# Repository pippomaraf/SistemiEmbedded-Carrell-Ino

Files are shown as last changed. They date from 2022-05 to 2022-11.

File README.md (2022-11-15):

# Carrell-Ino

### Descrizione

##### Autore

Filippo Maraffio

##### Descrizione

Il progetto prevede la realizzazione di un carrello elettrico automatico, in grado di spostare piccoli oggetti, lungo un percorso prefissato.

Il "Carrell-Ino" partirà automaticamente quando rileverà la presenza di un oggetto nel suo "cassone", e si muoverà seguendo una linea marcata precedentemente sul pavimento con del nastro isolante scuro.

Raggiunta la sua destinazione, il "Carrell-Ino" si fermerà, in attesa di essere scaricato.

Una volta che il suo cassone sarà libero, il "Carrell-Ino" tornerà al punto di partenza, pronto per essere caricato nuovamente.

##### Istruzioni di utilizzo

1. Tracciare un percorso, delineato da una linea scura, su una superficie chiara (ad esempio, utilizzare del nastro isolante nero su un pavimento di legno). Alle estremità del percoso posizionare delle sagome verticali (ad esempio, delle scatole di cartone)  per delimitare inizio e fine tratto.  Posizionare il "Carrell-Ino" a cavallo della linea che traccia il tragitto, ed accenderlo.

2. Posizionare un peso di almeno 50g sulla bilancia presente sul pannello superiore del "Carrell-Ino" ed attendere. Dopo pochi istanti, il carrello emetterà un segnale acustico e luminoso ed inizierà a muoversi.

3. Il "Carrell-Ino" si muoverà seguendo il percorso prefissato e si fermerà automaticamente una volta raggiunta la sua destinazione. Una luce rossa si accenderà per richiedere l'intervento dell'utente.

4. Girare il "Carrell-Ino", in modo tale da orientarlo verso il punto di partenza e premere il pulsante di cambio stato, posizionato vicino al sensore ad ultrasuoni.

5. Il "Carrell-Ino", dapprima resterà in attesa di essere scaricato; quando non rileverà più il peso sulla bilancia, ripartirà tornando al punto di inizio, dove si fermerà. 

6. Premendo il pulsante il "Carrell-Ino" tornerà al suo stato iniziale, e, dopo averlo riposizionato, sarà possibile caricarlo e farlo ripartire per effettuare ulteriori viaggi.

##### Calibrazione bilancia

Quando si installa una nuova cella di carico sul Carrell-Ino, è opportuno effettuare una calibrazione della bilancia, così da evitare comportamenti anomali.

Per la calibrazione, procurarsi un oggetto dal peso noto, collegare il Carrell-Ino a un PC dove è installato Arduino IDE, scommentare la costante `SCALE_CALIBRATION` e impostare `LOADCELL_DIVIDER` a `1`. Caricare quindi lo sketch modificato sulla board, aprire il serial monitor e seguire le istruzioni che compariranno a schermo.

Dopo aver effettuato tutti i passaggi, dividere il numero restituito dal serial monitor per il peso dell'oggetto usato per la calibrazione e usarlo come valore della costante `LOADCELL_DIVIDER`. Ricommentare `SCALE_CALIBRATION` e caricare nuovamente lo sketch sulla board. Il Carrell-Ino è pronto a partire!

##### Hardware utilizzato

- Board: Arduino Uno

- 4x modulo di rilevamento linea KY-033 (con sensore a infrarossi TCRT5000)

- 1x sensore a ultrasuoni HC-SR04

- 1x cella di carico 0-5kg

- 1x moudlo ADC HX711 (per amplificare e convertire il segnale della cella di carico)

- 1x Motor driver L298N

- 2x motori CC da 6V

- 5x batterie AA da 1.5V  (7.5V totali)

- 1x pulsante

- 1x diodo led

- 1x resistore da 1000 Ohm

- 1x  buzzer passivo

Per la la realizzazione del telaio e del ruotino di coda sono state utilizzate una  scatola di derivazione elettrica da incasso e una rotella girevole per mobili.

##### Librerie utilizzate

- [GitHub - bogde/HX711: An Arduino library to interface the Avia Semiconductor HX711 24-Bit Analog-to-Digital Converter (ADC) for Weight Scales.](https://github.com/bogde/HX711)

---

### Progettazione

Il programma che controlla il Carrell-Ino può essere descritto, ad alto livello, tramite il seguente automa a stati finiti:

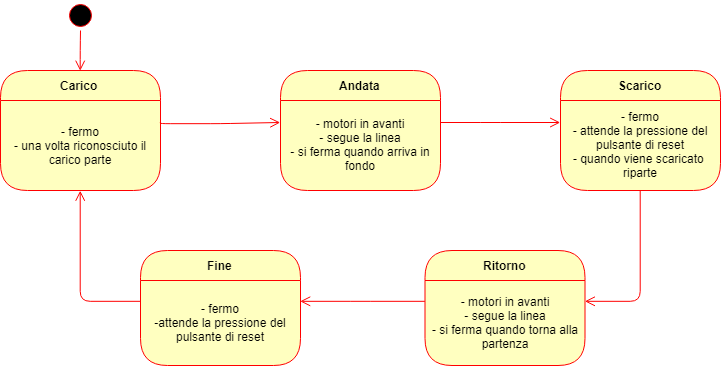
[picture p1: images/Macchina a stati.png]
Macchina a stati.png


_Schema della macchina a stati finiti utilizzata per gestire le varie fasi di esecuzione._

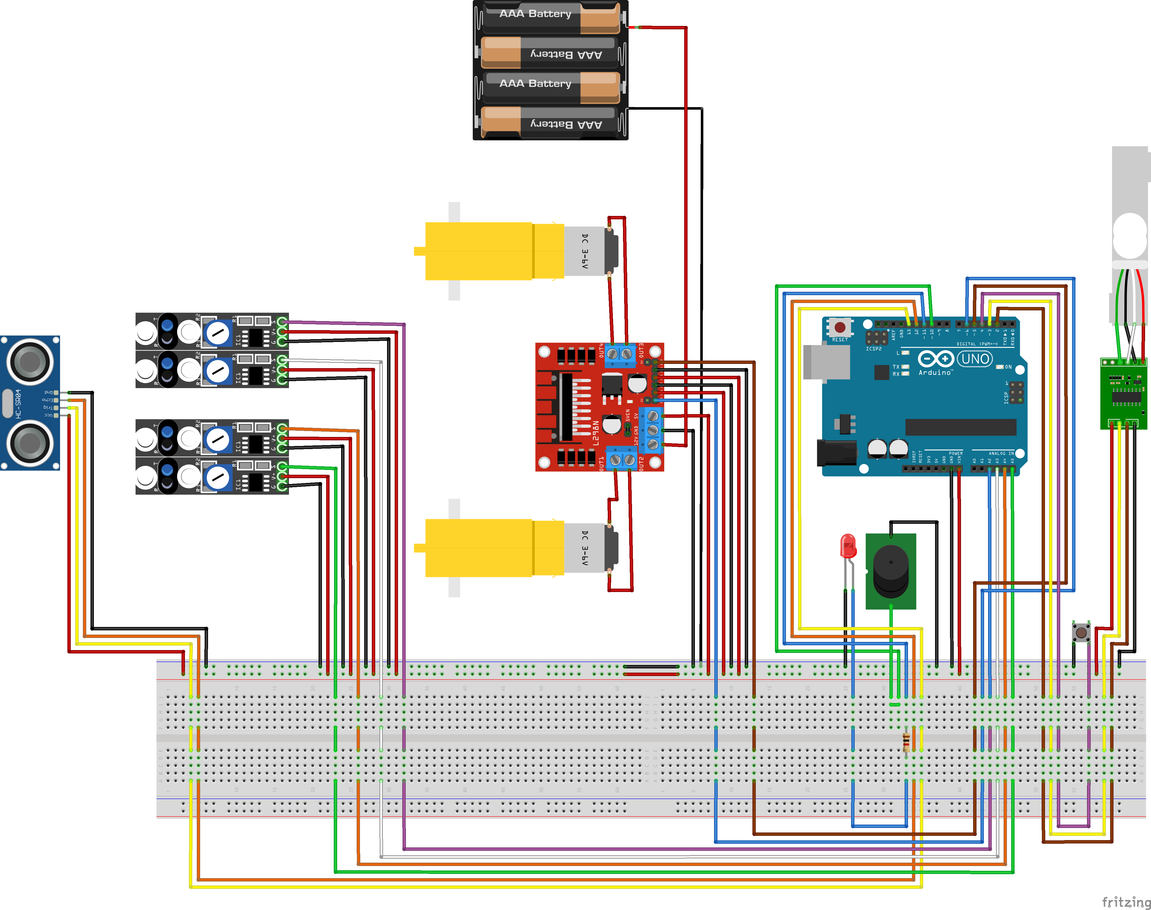
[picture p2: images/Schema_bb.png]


_Schema circuitale. Immagine creata con [Fritzing](https://fritzing.org/)_

---

### Foto e video

Un video del Carrell-Ino in funzione può essere trovato al seguente link: [Carrell-Ino - YouTube](https://www.youtube.com/watch?v=kGcqHUkBG_E)

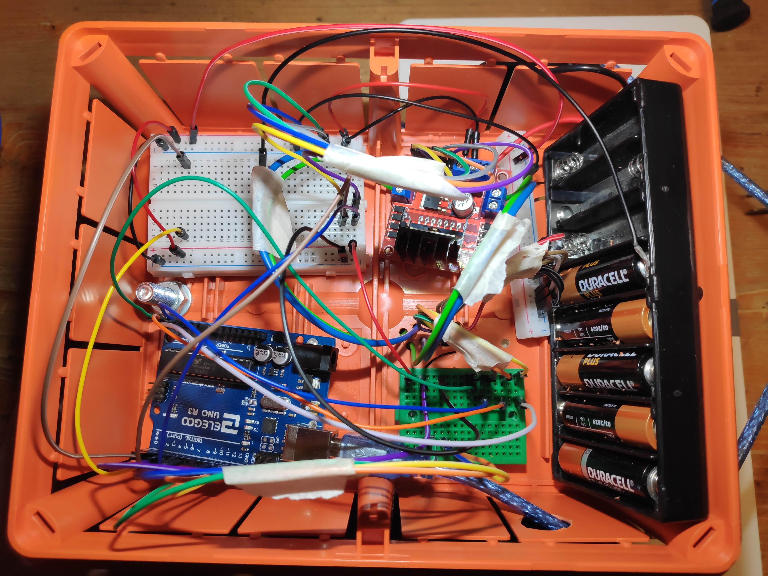
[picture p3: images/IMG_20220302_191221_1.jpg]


_Struttura interna del Carrell-Ino. Sono visibili la board Arduino Uno, il pacco batterie e il Motor Driver L298N._

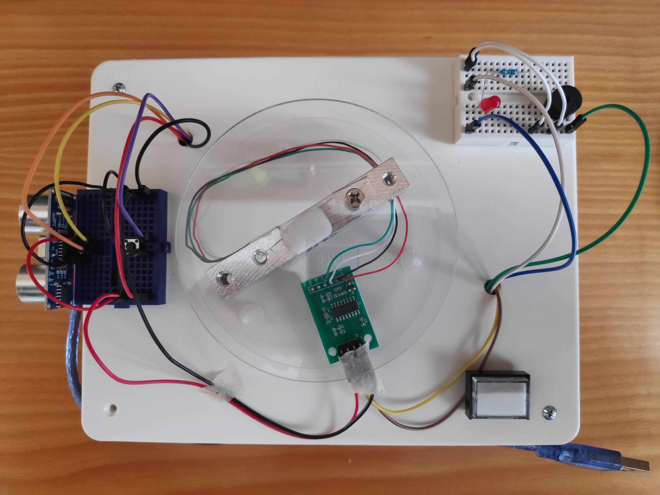
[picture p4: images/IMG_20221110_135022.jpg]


_Pannello superiore: sulla sinistra sono presenti il sensore a ultrasuoni e il pulsante per il cambio di stato, al centro si trova la cella di carico e il rispettivo moudlo ADC HX711, mentre a destra possiamo vedere il pulsante di accensione e il blocco di output._

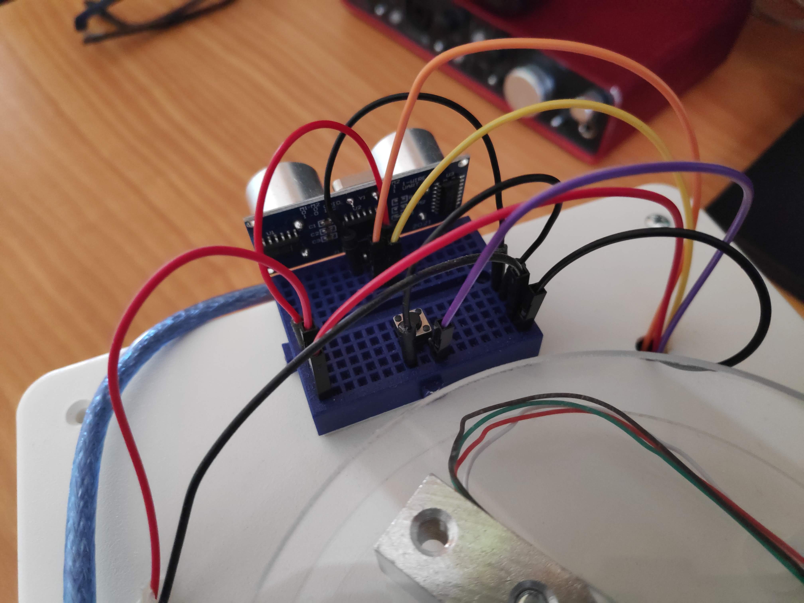
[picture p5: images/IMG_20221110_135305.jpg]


_Particolare del sensore a ultrasuoni e del pulsante di cambio stato._

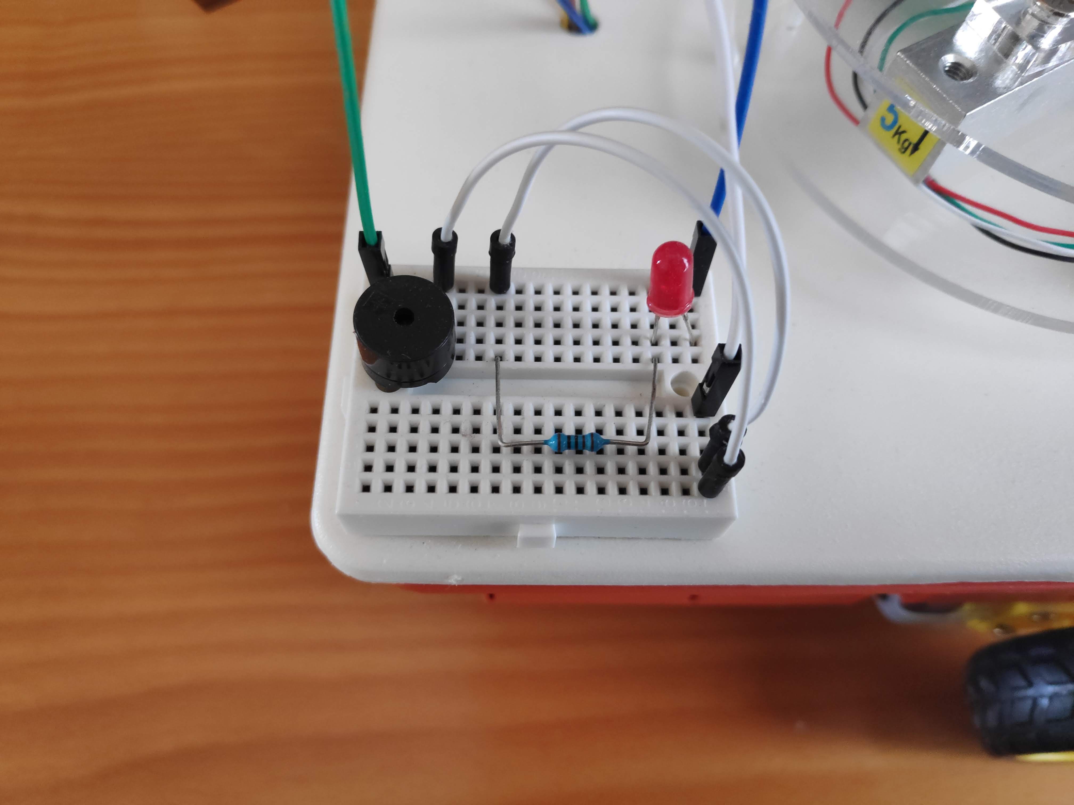
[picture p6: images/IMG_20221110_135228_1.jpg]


_Particolare del blocco di output: sono osservabili il diodo led con il suo resistore e il buzzer passivo._

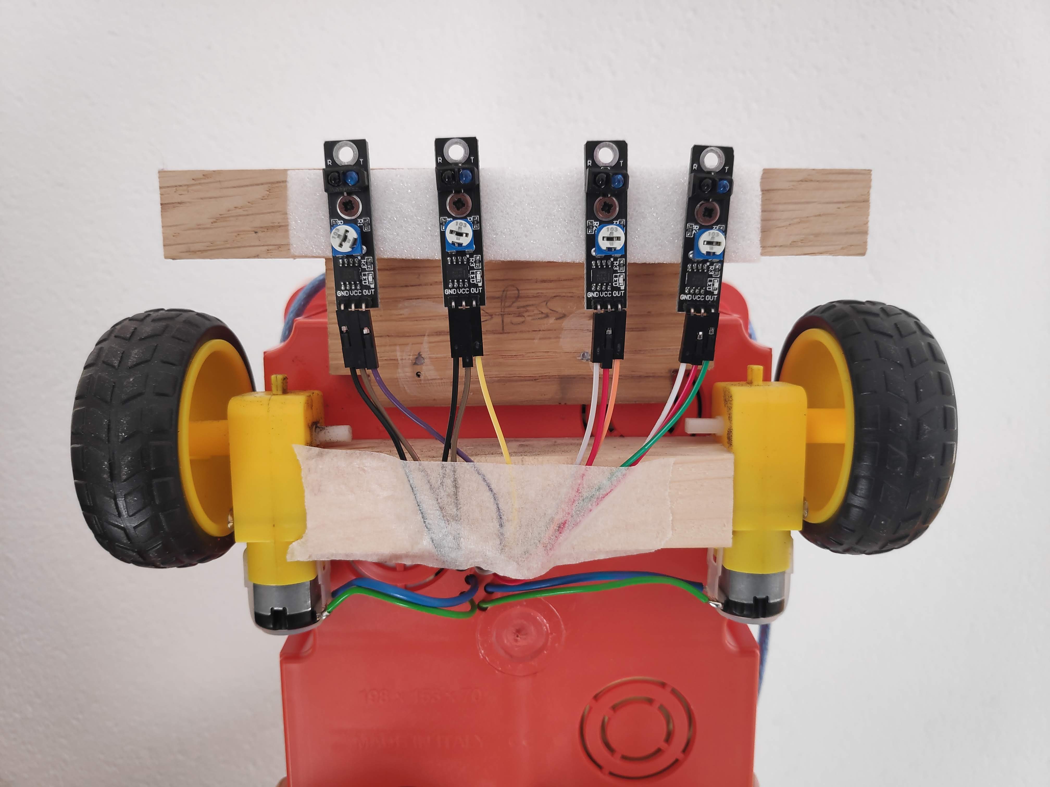
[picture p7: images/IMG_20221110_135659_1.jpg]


_Posizionamento dei moduli di rilevamento linea e dei due motori a corrente continua._

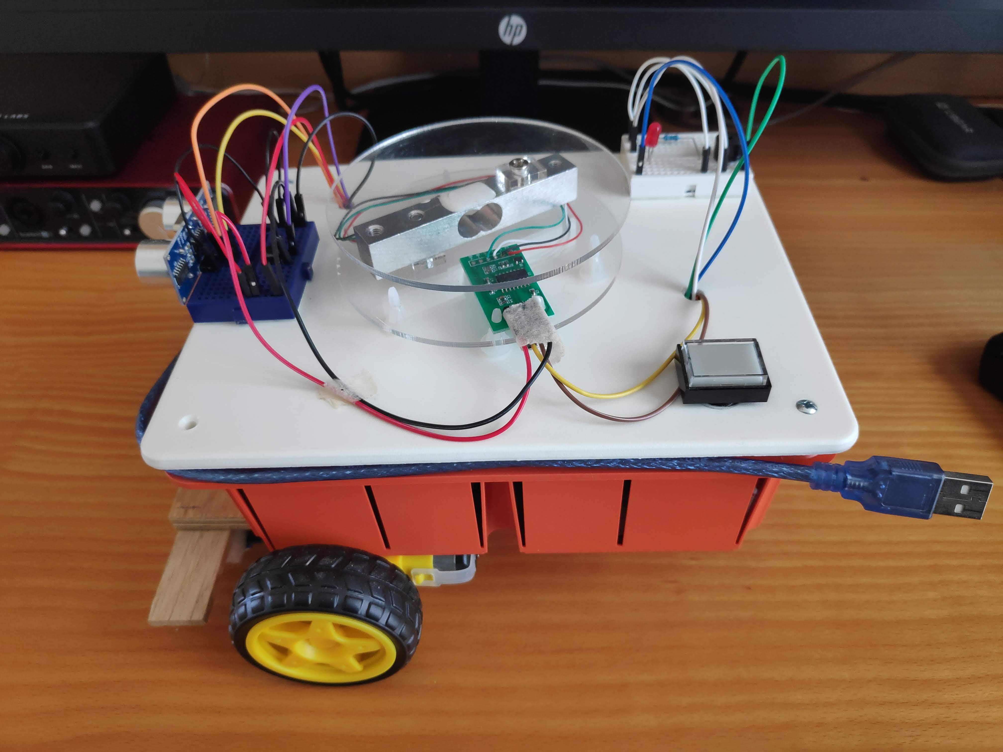
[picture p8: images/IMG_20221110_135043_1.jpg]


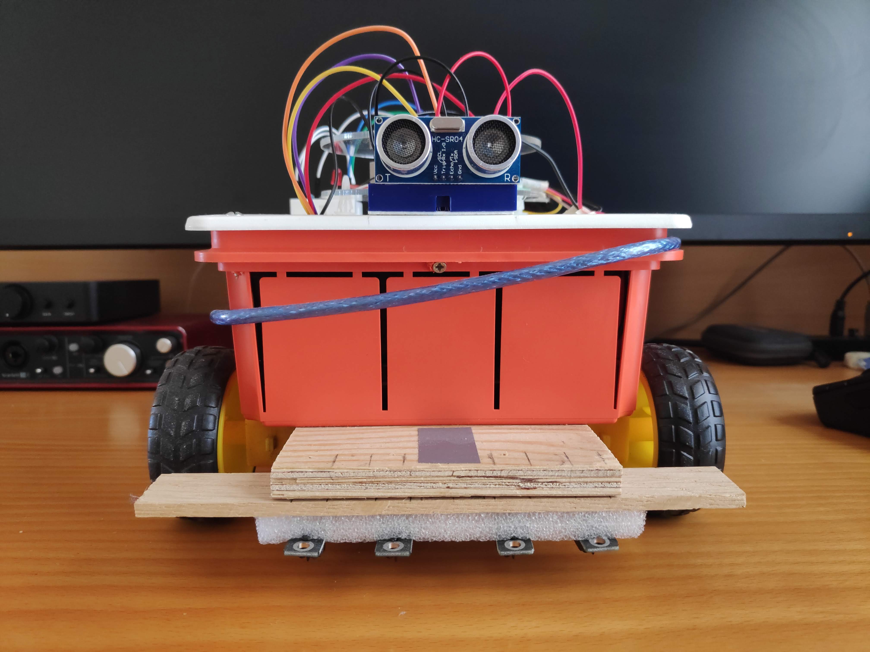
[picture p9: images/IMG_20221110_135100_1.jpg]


_Viste laterale e anteriore del Carrell-Ino._

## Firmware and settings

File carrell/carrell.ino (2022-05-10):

/**
 * @file carrell.ino
 * @author Filippo Maraffio
 * @brief Automatic, line-following electric cart
 * @version 1.0
 */

#include "HX711.h"
HX711 loadcell;

//-----------------------------
//      GPIO DEFINITIONS
//-----------------------------

// HC-SR04 ultrasonic sensor
#define ULTRASONIC_TRIG 13
#define ULTRASONIC_ECHO 12

// KY-033 line detecting sensor
// note: due to digital pin shortage, analog pins are used
// to perform digitalReads;
#define LINE_FOLLOWER_RR_SIGNAL A5
#define LINE_FOLLOWER_R_SIGNAL A4
#define LINE_FOLLOWER_L_SIGNAL A3
#define LINE_FOLLOWER_LL_SIGNAL A2

// L298N DC motor driver
// note: PWM capable pin needed
// note: the motors only need to move in one direction,
// IN pins are hard-coded (IN1 = IN3 = HIGH, IN2 = IN4 = LOW)
#define MOTOR_DRIVER_ENA 6
#define MOTOR_DRIVER_ENB 5

// HX711 load cell module
#define LOAD_CELL_CK 3
#define LOAD_CELL_DATA 2

// led
#define LED_PIN 11

// button
#define BUTTON_PIN 4

// buzzer
#define BUZZER_PIN 10

//-----------------------------
//      CONSTANTS
//-----------------------------

// uncomment to calibrate the scale
// #define SCALE_CALIBRATION

// load cell calibration, calculated with the calibrateScale() function
#define LOADCELL_DIVIDER 497.5
#define LOADCELL_READ_TIMES 10

// found by trial and error
#define MINIMUM_SPEED 120 // PWM value, out of 255
#define NORMAL_SPEED 130
#define TUNRING_SPEED 20
#define BRAKE_DELAY 3 // milliseconds

// note: measure errors are present. Consider the minimum weight
// to be 10g above this treshold
#define MINIMUM_WEIGHT_TRESHOLD 40

// how many readings of the loadcell to do
#define LOADCELL_READS 10

// number of loadcell reds under the treshold before
// the carrell.ino will start moving
#define CHECKS_BEFORE_START 3

// for stability
#define STABILITY_DELAY 50

// for ultrasonic sensor
#define CLEAR_TIME 2    // microseconds
#define TRIGGER_TIME 10 // microseconds

// number of centimeters travelled by sound in a microsecond
#define CM_MULTIPLIER 0.034326
// 2, to take in consideration the fact that sound has to travel doble the
// distance to go and come back
#define RTT_MULTIPLIER 2
#define STOPPING_DISTANCE 25L // centimeters
#define ERROR_DISTANCE 2L     // centimeters

// return value
#define SUCCESS 1
#define FAILURE -1

//-----------------------------
//      FUNCTIONS
//-----------------------------

/* L298N Motor driver
  Existing libraries are way too complex for what we'll need, so we'll just
  define a couple of functions.

  Our project only needs to move forward, so pins 1,2,3 and 4 are hard-coded
*/
void moveForward(int speed)
{
  analogWrite(MOTOR_DRIVER_ENA, speed);
  analogWrite(MOTOR_DRIVER_ENB, speed);
}

void steer(int speedLeft, int speedRight)
{
  analogWrite(MOTOR_DRIVER_ENA, speedLeft);
  analogWrite(MOTOR_DRIVER_ENB, speedRight);
}

// gently slow down
void stop()
{
  for (int i = NORMAL_SPEED; i >= 0; i--)
  {
    moveForward(i);
    delay(BRAKE_DELAY);
  }
}

/* Tunes
 * the function tone() is used. If you are interested to better understand the
 * tunes, tone(PIN, FREQUENCY, DURATION) plays a tone at FREQUENCY Hz for
 * DURATION ms -> es:   tone(BUZZER_PIN, 494, 700); plays a tune at 494Hz
 * for 700ms
 */
void arrivalTune()
{
  digitalWrite(LED_PIN, HIGH);
  delay(50);
  digitalWrite(LED_PIN, LOW);
  tone(BUZZER_PIN, 494, 700); // B4
  delay(80);

  digitalWrite(LED_PIN, HIGH);
  delay(50);
  digitalWrite(LED_PIN, LOW);
  tone(BUZZER_PIN, 659, 600); // E5
  delay(80);

  digitalWrite(LED_PIN, HIGH);
  delay(50);
  digitalWrite(LED_PIN, LOW);
  tone(BUZZER_PIN, 740, 600); //  F#5
  delay(80);

  digitalWrite(LED_PIN, HIGH);
  tone(BUZZER_PIN, 988, 850); // B5
  delay(850);
  digitalWrite(LED_PIN, LOW);
}

void startTune()
{
  for (int i = 0; i <= 3; i++)
  {
    digitalWrite(LED_PIN, HIGH);
    tone(BUZZER_PIN, 1319, 200); // E6
    delay(200);
    tone(BUZZER_PIN, 1397, 200); // F6
    delay(200);
    digitalWrite(LED_PIN, LOW);
    tone(BUZZER_PIN, 2637, 200); // E7
    delay(200);
    tone(BUZZER_PIN, 2794, 200); // F7
    delay(200);
  }
}

/** Scale
 * to initialize the scale, uncomment the SCALE_CALIBRATION definition and set
 * LOADCELL_DIVIDER to 1.
 */
void calibrateScale()
{
  // calibration start
  bool stopped;
  Serial.println("Begin calibration. Please remove any weight on the scale.");
  Serial.println("Send anything from serial monitor when you are ready");
  stopped = true;
  // clear serial
  while (Serial.available())
  {
    char foo = Serial.read();
  }
  while (stopped)
  {
    if (Serial.available() > 0)
    {
      stopped = false;
    }
  }
  loadcell.tare();
  Serial.println("Put a known weight on the scale, then send anything from the serial monitor");
  stopped = true;
  // clear serial
  while (Serial.available())
  {
    char foo = Serial.read();
  }
  while (stopped)
  {
    if (Serial.available() > 0)
    {
      stopped = false;
    }
  }
  Serial.print("Weight: ");
  Serial.println(loadcell.get_units(LOADCELL_READ_TIMES), 2); // limit to two numbers afer comma
  Serial.println("Divide this for the known weight and set LOADCELL_DIVIDER accordingly");
  Serial.println("Calibration ended");
}

/** LINE FOLLOWER
 * @brief moves forward at the given speed. Carrell.ino will try it's best to
 * follow a dark line on a light surface, using its infrared sensors. To
 * function properly this function should be cycled for the time that you
 * intend the carrell.ino to follow the line. Keep in mind that the infrared
 * sensor are checked in order every cycle, the busyer the cycle you put this
 * function in the slower the carrell.ino will respond!
 */
void followLine(int speed)
{
  // when R sensor is on the line, for the time that it reads the line
  // gently steer right
  if (digitalRead(LINE_FOLLOWER_R_SIGNAL))
  {
    while (digitalRead(LINE_FOLLOWER_R_SIGNAL))
    {
      steer(speed, TUNRING_SPEED);
      // if it gets stuck, break out of the cycle
      if (digitalRead(LINE_FOLLOWER_L_SIGNAL))
        break;
      // if it's very off, steer hard until the left sensor is on the line
      if (digitalRead(LINE_FOLLOWER_RR_SIGNAL))
      {
        while (!digitalRead(LINE_FOLLOWER_L_SIGNAL))
        {
          steer(MINIMUM_SPEED, 0);
        }
      }
    }
  }
  // when L sensor is on the line, for the time that it reads the line
  // gently steer left
  else if (digitalRead(LINE_FOLLOWER_L_SIGNAL))
  {
    while (digitalRead(LINE_FOLLOWER_L_SIGNAL))
    {
      steer(TUNRING_SPEED, speed);
      // if it gets stuck, break out of the cycle
      if (digitalRead(LINE_FOLLOWER_R_SIGNAL))
        break;
      // if it's very off, steer hard until the right sensor is on the line
      if (digitalRead(LINE_FOLLOWER_LL_SIGNAL))
      {
        while (!digitalRead(LINE_FOLLOWER_R_SIGNAL))
        {
          steer(0, MINIMUM_SPEED);
        }
      }
    }
  }
  // if it's very off, steer hard until it's straight again
  else if (digitalRead(LINE_FOLLOWER_RR_SIGNAL))
  {
    while (!digitalRead(LINE_FOLLOWER_L_SIGNAL))
    {
      steer(MINIMUM_SPEED, 0);
    }
  }
  else if (digitalRead(LINE_FOLLOWER_LL_SIGNAL))
  {
    while (!digitalRead(LINE_FOLLOWER_R_SIGNAL))
    {
      steer(0, MINIMUM_SPEED);
    }
  }
  // otherwise, go straight
  else if (!digitalRead(LINE_FOLLOWER_R_SIGNAL) && !digitalRead(LINE_FOLLOWER_L_SIGNAL))
    moveForward(speed);
}

/** ULtrasoun sensor
 * @brief check if a wall is near in front of the carrell.ino
 * Stop if needed
 */
int stopIfNearWall()
{
  // start in a safe state
  digitalWrite(ULTRASONIC_TRIG, LOW);
  delayMicroseconds(CLEAR_TIME);

  // send ultrasonic signal
  digitalWrite(ULTRASONIC_TRIG, HIGH);
  delayMicroseconds(TRIGGER_TIME);
  digitalWrite(ULTRASONIC_TRIG, LOW);

  // read echo value, in microseconds
  long duration = pulseIn(ULTRASONIC_ECHO, HIGH, 2000);

  // Calculating the distance in cm
  long distance = duration * CM_MULTIPLIER / RTT_MULTIPLIER;

  // if there are less than the desired distance, stop and go to unloading state
  if (distance > ERROR_DISTANCE && distance < STOPPING_DISTANCE)
  {
    stop();
    return SUCCESS;
  }
  return FAILURE;
}

//-----------------------------
//      STATES
//-----------------------------
/**
 * @brief the carrell.ino is stopped. Once a load of at least
 * 50 grams is put on the
 * scale, the start sequence will be played
 */
void loadingState()
{
  long weight = 0L;
  int times = CHECKS_BEFORE_START;

  while (times >= 0)
  {
    Serial.println(times);
    Serial.print("Weight: ");
    weight = loadcell.get_units(LOADCELL_READS);
    Serial.println(weight);
    if (weight >= MINIMUM_WEIGHT_TRESHOLD)
    {
      times--;
    }
    else
    {
      times = CHECKS_BEFORE_START;
    }
  }
  startTune();
}

/**
 * @brief carrell.ino starts moving. It will follow a black line on the floor,
 * and it will stop when a  wall is near in front of it.
 */
void wayThereState()
{
  // start moving forward
  while (true)
  {
    followLine(NORMAL_SPEED);
    int returnValue = stopIfNearWall();
    if (returnValue == SUCCESS)
      break;
  }
}

/**
 * @brief the carrell.ino has stopped. First, you'll need to turn it around
 * (due to the limited number of GPIO the carrell.ino does not have a symmetric
 * structure), then you'll need to press the button near the ultrasonic sensor.
 * The carrell.ino will wait to be unloaded, then it will go back to where it
 * started its run.
 */
void unloadingState()
{
  // wait until the reset button is pressed
  while (true)
  {
    if (!digitalRead(BUTTON_PIN))
    {
      break;
    };
    digitalWrite(LED_PIN, HIGH);
    delay(STABILITY_DELAY);
  }
  digitalWrite(LED_PIN, LOW);

  long weight = 0L;
  int times = CHECKS_BEFORE_START;

  while (times >= 0)
  {
    weight = loadcell.get_units(LOADCELL_READS);
    if (weight <= MINIMUM_WEIGHT_TRESHOLD)
    {
      times--;
    }
    else
    {
      times = CHECKS_BEFORE_START;
    }
  }
  startTune();
}

void wayBackState()
{
  while (true)
  {
    followLine(NORMAL_SPEED);
    int returnValue = stopIfNearWall();
    if (returnValue == SUCCESS)
      break;
  }
}

void finishState()
{
  arrivalTune();
  while (true)
  {
    if (!digitalRead(BUTTON_PIN))
      break;
    delay(STABILITY_DELAY);
  }
}

//-----------------------------
//      LOOP AND SETUP
//-----------------------------

void setup()
{
  // pin modes
  pinMode(ULTRASONIC_TRIG, OUTPUT);
  pinMode(ULTRASONIC_ECHO, INPUT);
  pinMode(LINE_FOLLOWER_RR_SIGNAL, INPUT);
  pinMode(LINE_FOLLOWER_R_SIGNAL, INPUT);
  pinMode(LINE_FOLLOWER_L_SIGNAL, INPUT);
  pinMode(LINE_FOLLOWER_LL_SIGNAL, INPUT);
  pinMode(MOTOR_DRIVER_ENA, OUTPUT);
  pinMode(MOTOR_DRIVER_ENB, OUTPUT);
  loadcell.begin(LOAD_CELL_DATA, LOAD_CELL_CK);
  loadcell.set_scale(LOADCELL_DIVIDER);
  loadcell.tare();
  pinMode(LED_PIN, OUTPUT);
  pinMode(BUTTON_PIN, INPUT_PULLUP);
  pinMode(BUZZER_PIN, OUTPUT);

  // serial monitor (for developement purposes)
  Serial.begin(9600);

// scale calibration
#ifdef SCALE_CALIBRATION
  calibrateScale();
#endif
}

void loop()
{
  loadingState();
  wayThereState();
  unloadingState();
  wayBackState();
  finishState();
}

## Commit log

2022-05-09 carrell.ino now can stop using his ultrasound sensor
2022-05-10 Updated README and added cirtuit scheme
    [Schema.fzz]
2022-11-10 readme: add scale calibration instructions
